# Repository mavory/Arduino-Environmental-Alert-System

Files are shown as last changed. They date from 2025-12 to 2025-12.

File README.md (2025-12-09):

# Arduino Environmental Alert System

It is a system that will allow you to monitor the temperature and humidity in your apartment, for example. It is very easy to set up and allows you to do a lot of things.

## Why did I do this?

I wanted to create some project with Arduino that could measure temperature and humidity and then send it to a PC. I also wanted to experiment and this seemed like a good idea.

## Features

- Ability to send emails
- Ability to create graphs and data into tables
- 24/7 monitoring possible
- Buzzer warning when limits are exceeded

## Scripts

Everything works on the Arduino code, which collects data and then the Python code on the PC monitors it.

## How it works?

The DHT11 sends information to the Arduino, which is programmed to send information at 9600. It is then taken over by python code, which monitors the information and if the temperature/humidity is outside the allowed range, it sends an email!

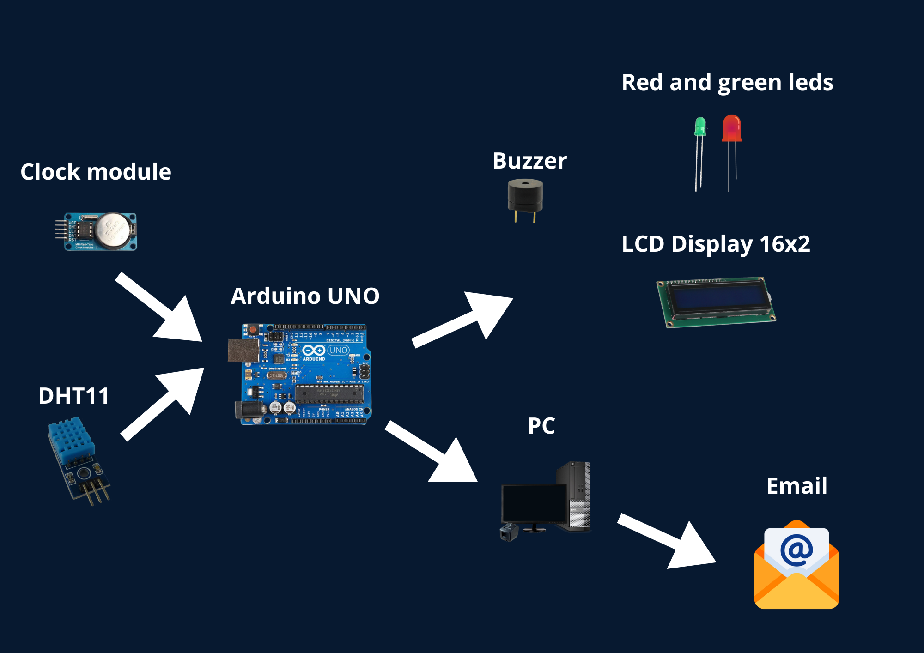
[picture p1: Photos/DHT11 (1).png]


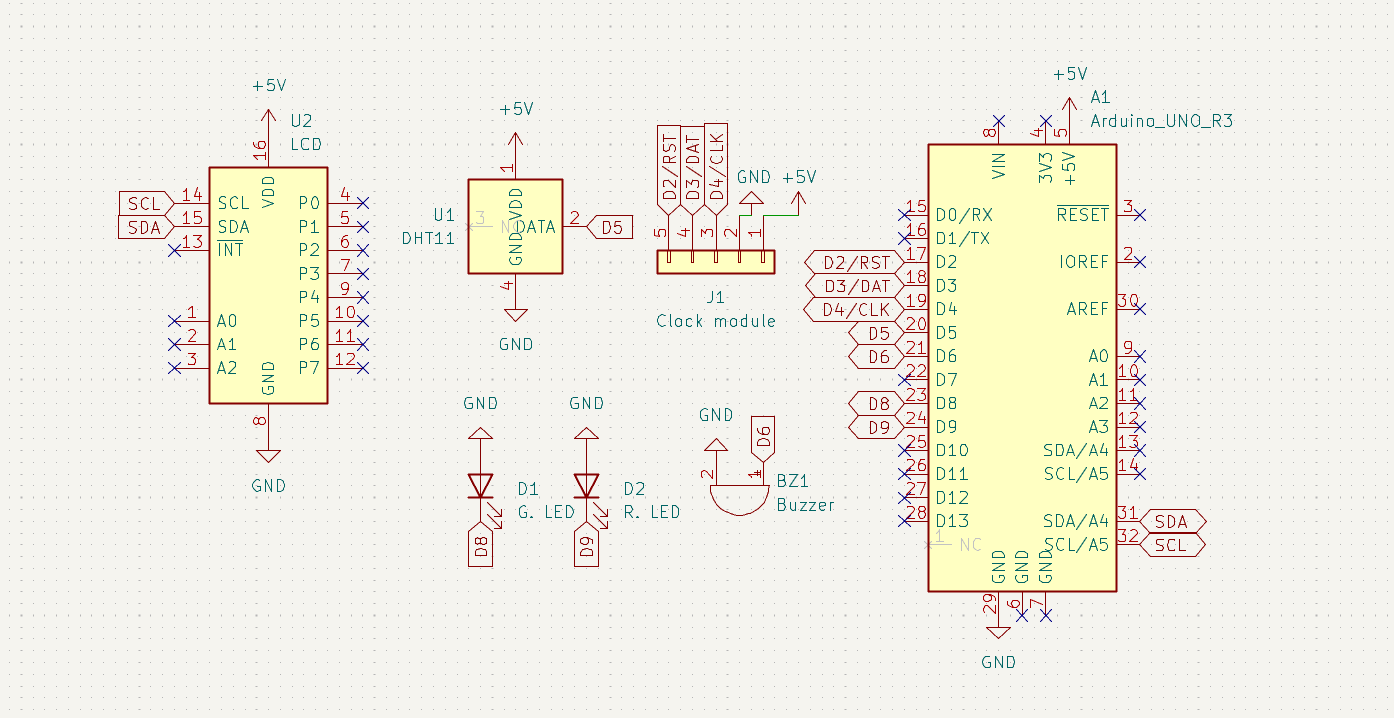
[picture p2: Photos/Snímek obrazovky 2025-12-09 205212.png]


## 3D models

Here is a view of the top and bottom of the case:

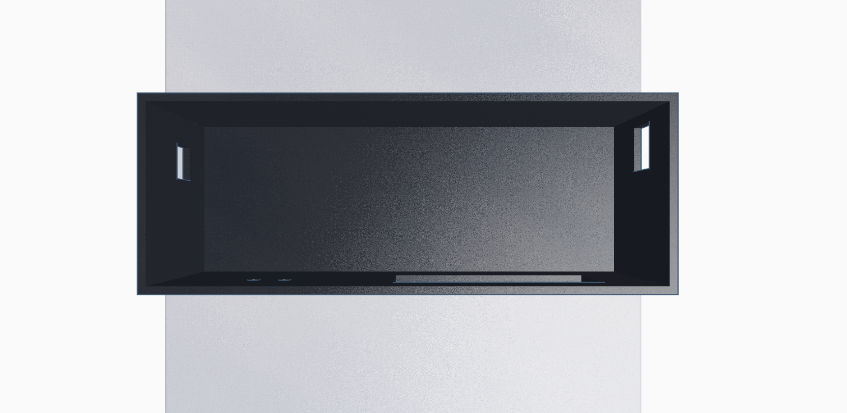
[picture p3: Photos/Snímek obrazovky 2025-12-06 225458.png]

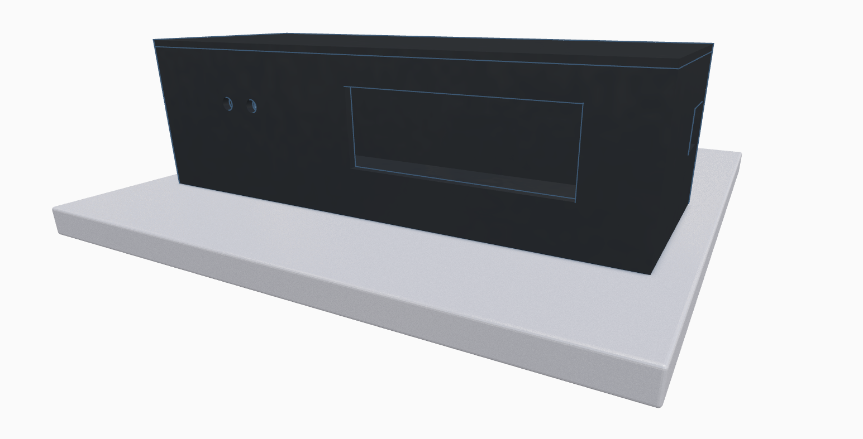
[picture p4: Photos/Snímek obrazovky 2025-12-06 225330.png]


## Here is the final image of how it works!



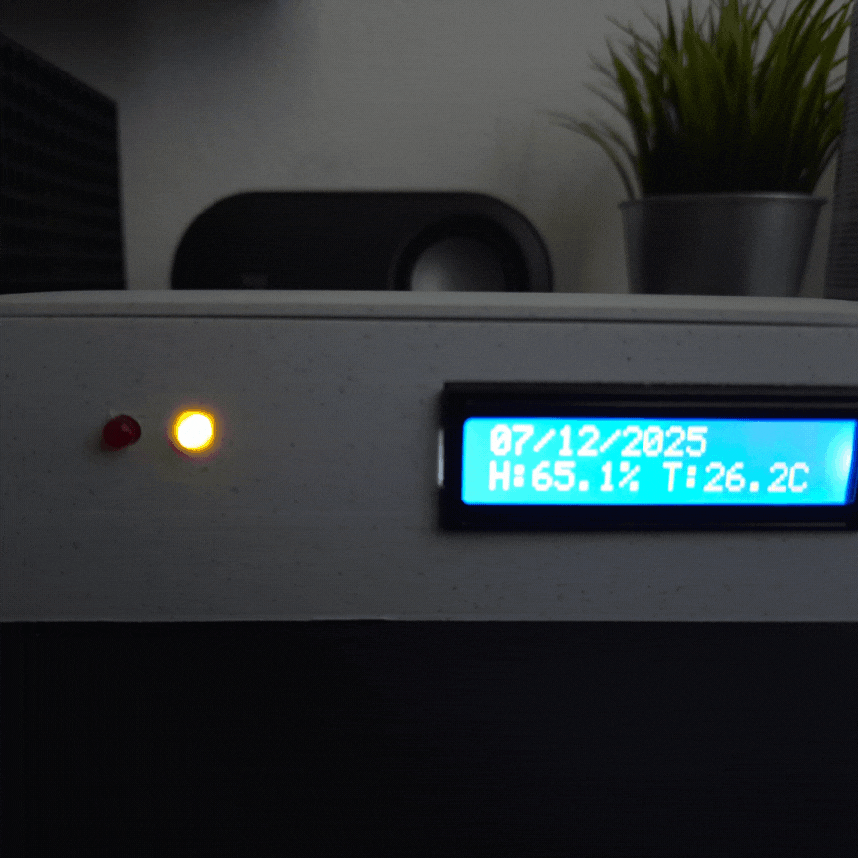
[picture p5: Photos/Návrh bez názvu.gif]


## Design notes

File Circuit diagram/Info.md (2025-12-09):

# Wiring
### DHT11 Sensor

- GND: GND
- VCC: 5V
- DATA: D5

### LCD Display

- GND: GND
- VCC: 5V
- SDA: A4
- SCL: A5

### Buzzer

- Pin: D6
- GND: GND

### Green and red led

- Green: D8
- Red: D9
- GND: GND

### Clock module

- GND: GND
- VCC: 5V
- CLK: D4
- DAT: D3
- RST: D2

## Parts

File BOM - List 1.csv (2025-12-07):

Item | Quantity | Link
Arduino UNO R3 | 1 | https://www.aliexpress.com/item/1005009161334072.html?curPageLogUid=n2sKRZSiC7X8
Green led | 1 | https://www.aliexpress.com/item/1005004453741169.html?scm_id=1007.14452.396806.0&scm-url=1007.14452.396806.0
Red led | 1 | https://www.aliexpress.com/item/1005004453741169.html?scm_id=1007.14452.396806.0&scm-url=1007.14452.396806.0
Breadboard | 1 | https://www.aliexpress.com/item/1005009799908389.html
DHT11 | 1 | https://www.aliexpress.com/item/32997407491.html?curPageLogUid=FQjsx9HCVnmy
Buzzer | 1 | https://www.aliexpress.com/item/1005010321957502.html?curPageLogUid=pNY8QTDdxUFY
Cables | Much | https://www.aliexpress.com/item/1005002611994443.html?curPageLogUid=fx2zB0EGcu5H
LCD 16x2 | 1 | https://www.aliexpress.com/item/1005010345517169.html?curPageLogUid=SbTSyaXiciNx
RTC module | 1 | https://www.aliexpress.com/item/32948191960.html?curPageLogUid=74KaBoIFDABx

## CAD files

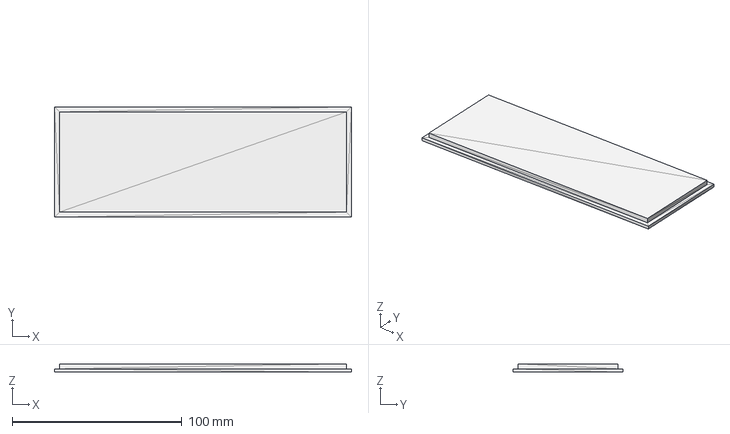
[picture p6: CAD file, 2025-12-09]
CAD/Top.step
175.0 x 65.0 x 5.00 mm

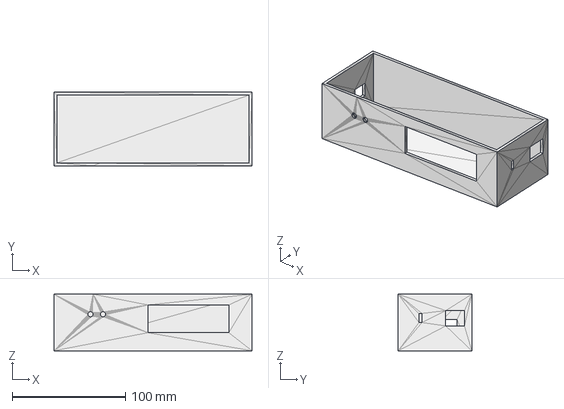
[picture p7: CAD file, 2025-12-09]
CAD/Bottom.step
175.0 x 65.0 x 50.0 mm

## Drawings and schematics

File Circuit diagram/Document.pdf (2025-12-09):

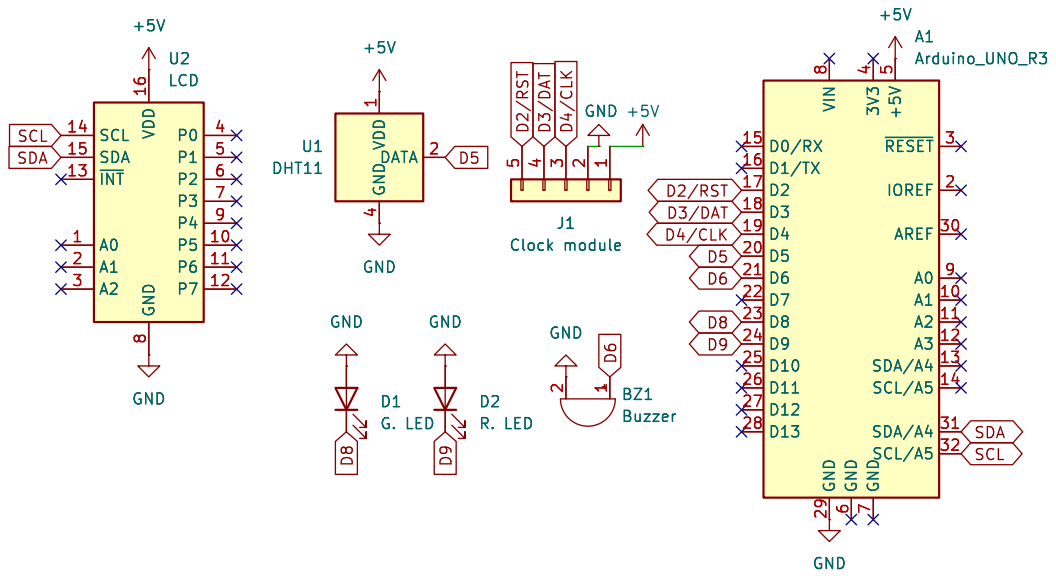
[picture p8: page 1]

1BZ1 Buzzer +5V +5V GND GND GND D2 R. LED GND VDD

4 DATA U1 2 DHT11 D0/RX 15 D1/TX 16 D2 17 D3 18 D4 19 D5 20 D6 21 D7 22 D8 23 D9 24 D10 25 D11 26 D12 27 D13 28 VIN

Id: 1/1 Title: File: New.kicad_sch Sheet: / D1 G. LED

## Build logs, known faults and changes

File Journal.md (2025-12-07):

# My Journal

This is the journal where I created a project with Arduino.

## So how much time did I spend on that?

In total, I spent about over 13 hours on it...

## My worst hangups

- I couldn't even put the leds in the holes, so I had to grind it all down.
- The RTC module was also giving me weird dates, but I fixed that.
- I made a few coding mistakes.

## Timeline

I thought I would create a system that would monitor temperature and humidity using Arduino and then send the information to Gmail. First I drew everything and started working on it:



Next, I started creating a GitHub repo and created folders. I also found all the parts so I could put it together. I thought for a while about using RTC, but I got over it and used it.



I started testing all the components to see if they worked. The LCD worked, the Buzzer too... But I forgot to set the RTC, so it told me that today is the year 2087 😭

This: 2087-31-12 03:27:00

I solved the problem by resetting the RTC and I was able to continue building.



After testing the components, I jumped into making the 3D case. I took all my measurements and started modeling the bottom part. I gave each piece a small tolerance so it would fit nicely. When I had the bottom finished, I just tried it out to see if everything fit and it did! So I moved on to the top part, which was easy to model.



When I had the 3D case ready, I started connecting the components. A few times some of the cables fell out, but that was probably the worst problem.



Unfortunately I found a minor problem that I hadn't noticed before. The DHT11 connection is completely extruded, so I had to adjust a few things on the bottom and it should be good now.

After editing the 3D case, I jumped into coding the Arduino. I just wanted the basic logic for the system to send information to the serial monitor, which would then be taken over by the python code, which would then do more things.
I experimented with libraries a few times, but after a while I decided to use the ones in the picture now.



Once I had the code without errors (hopefully), I could start testing if everything is working properly. I tested if the RTC is showing a good date, and it is. I also tested the sensor to see if it is sending good information and it seems that everything is working perfectly so far!
In the meantime, I printed the bottom part so it would be finished as soon as possible.



Meanwhile, while the bottom part was printing, I started creating python code that would take values from the Arduino and then send emails using Google Code. At first I didn't know how to do it, but then I added things gradually and it became a working code.

When the bottom part was printed, I took it off the printer and prepared a breadboard and components so I could put them inside. It all worked out, but there were a few problems...
The holes for the LEDs were too small, so I had to grind them down and they ended up getting in there. I also kept disconnecting the cables from the components, but I fixed that. Then I had it all ready and tested to see if everything worked. And it did!
Just print the top part, tweak a few things, set the code and everything should hopefully work.



I already printed the top part. I put it on top of it and it fit perfectly. I saved the Python code and created a code in Google settings so I could send emails.I was looking for that setting for a while, but after some time I found it.

After about 13 hours of work, I finished this project. Everything works and fits.
I'm very glad it works!

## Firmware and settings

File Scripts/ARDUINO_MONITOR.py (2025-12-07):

import serial
import time
import csv
import pandas as pd
import matplotlib.pyplot as plt
from datetime import datetime
from email.mime.multipart import MIMEMultipart
from email.mime.image import MIMEImage
import os
# Poznámka: smtplib, MIMEText se importují až ve funkci.

# --- SETTINGS ---
PORT = "COM3"
RATE = 9600
MAIL_FROM = "EMAIL!!!"
APP_PASS = "GOOGLE CODE!!!" # Zabezpečené heslo aplikace

# --- TARGETS & FILES ---
MAIL_TO = "EMAIL!!!!"
CSV_FILE = "data.csv"
H_GRAPH = "humid_graph.png"
T_GRAPH = "temp_graph.png"

# --- LIMITS ---
H_min = 30.0
H_max = 70.0
T_min = 15.0
T_max = 30.0

# state: 1=OK, 0=OUT_OF_LIMIT
H_state = 1
T_state = 1

def send_report(subject, body_html, attachments=None):
    
    import smtplib
    from email.mime.text import MIMEText
    
    msg = MIMEMultipart('related') 
    msg['Subject'] = subject
    msg['From'] = MAIL_FROM
    msg['To'] = MAIL_TO
    
    msg.attach(MIMEText(body_html, 'html'))

    # Poznámka: Prilohy se posilaji pouze pri alarmech/navratu
    if attachments:
        for attachment_path in attachments:
            if not os.path.exists(attachment_path):
                print(f"ERROR: Attachment file not found: {attachment_path}")
                continue
            
            with open(attachment_path, 'rb') as f:
                img = MIMEImage(f.read())
                
            img.add_header('Content-ID', f'<{os.path.basename(attachment_path)}>')
            msg.attach(img)


    try:
        s = smtplib.SMTP_SSL('smtp.gmail.com', 465)
        s.login(MAIL_FROM, APP_PASS)
        s.send_message(msg)
        s.quit()
        print("INFO: Email OK.")
    except Exception as e:
        print(f"ERROR: Email failed: {e}")

def get_data(line):
    
    try:
        line = line.strip()
        
        if "H:" in line and "T:" in line:
            
            # jednodussi parsovani, vice chybove (pozn.: lidska chyba)
            parts = line.split(" ") 
            
            hum = float(parts[0].replace("H:", ""))
            temp = float(parts[1].replace("T:", ""))

            return hum, temp

        if "ERROR" in line:
            print("ERROR: Sensor reported an issue.")
            return None

    except Exception as e:
        print(f"ERROR: Parsing error on line '{line}': {e}")
        
    return None

def check_limits(humidity, temperature):
    global H_state, T_state

    # Priprava tela zprava (HTML) a casu udalosti
    event_time = datetime.now().strftime("%Y-%m-%d %H:%M:%S")
    
    # HTML s inline obrazky
    body_template = f"""
    <html>
    <body style="font-family: Arial, sans-serif; font-size: 14px;">
        <h2 style="color: #333;">Monitoring Report</h2>
        <ul style="list-style-type: none; padding: 0;">
            <li style="margin-bottom: 5px;"><b>EVENT TIME:</b> {event_time}</li>
            <li style="margin-bottom: 5px;"><b>Current Humidity:</b> {humidity:.1f}% (Limit: {H_min}% - {H_max}%)</li>
            <li style="margin-bottom: 10px;"><b>Current Temperature:</b> {temperature:.1f}&#8451; (Limit: {T_min}&#8451; - {T_max}&#8451;)</li>
            <li><b>Status:</b> {{status}}</li>
        </ul>
        <hr>
        
        <h3 style="color: #555;">Recent Data Overview:</h3>
        <p><b>Humidity:</b></p>
        <img src="cid:{H_GRAPH}" alt="Humidity Graph">
        <p><b>Temperature:</b></p>
        <img src="cid:{T_GRAPH}" alt="Temperature Graph">
        
    </body>
    </html>
    """
    
    attachments = [H_GRAPH, T_GRAPH]


    # 1. Humidity Check
    if humidity < H_min or humidity > H_max:
        if H_state != 0:
            H_state = 0
            
            # ALARM
            subject = "ALARM: Humidity Out of Range!"
            body = body_template.replace("{{status}}", '<span style="color:red; font-weight:bold;">HUMIDITY OUT OF LIMIT</span>')
            send_report(subject, body, attachments) # Poslat s prilohou
            
    elif H_state != 1:
        H_state = 1
        
        # RETURN TO NORMAL
        subject = "INFO: Humidity Back to Normal"
        body = body_template.replace("{{status}}", '<span style="color:green; font-weight:bold;">All within normal range</span>')
        send_report(subject, body, attachments) # Poslat s prilohou
        
        
    # 2. Temperature Check
    if temperature < T_min or temperature > T_max:
        if T_state != 0:
            T_state = 0
            
            # ALARM
            subject = "ALARM: Temperature Out of Range!"
            body = body_template.replace("{{status}}", '<span style="color:red; font-weight:bold;">TEMPERATURE OUT OF LIMIT</span>')
            send_report(subject, body, attachments) # Poslat s prilohou
            
    elif T_state != 1:
        T_state = 1
        
        # RETURN TO NORMAL
        subject = "INFO: Temperature Back to Normal"
        body = body_template.replace("{{status}}", '<span style="color:green; font-weight:bold;">All within normal range</span>')
        send_report(subject, body, attachments) # Poslat s prilohou


def csv_write(h, t):
    
    now = datetime.now()
    try:
        with open(CSV_FILE, mode='a', newline='') as f:
            csv_writer = csv.writer(f)
            csv_writer.writerow([now.strftime("%Y-%m-%d %H:%M:%S"), h, t])
    except Exception as e:
        print(f"ERROR: CSV write failed: {e}")

def graph_make():
    try:
        # Poznámka: Jde o rychlou a ne moc cistou implementaci Pandas/Matplotlib
        df = pd.read_csv(CSV_FILE, header=None, names=["time", "H", "T"], parse_dates=["time"])
        
        # H graph
        plt.figure(figsize=(7, 3.5)) 
        plt.plot(df["time"], df["H"])
        plt.title("H Humidity")
        plt.grid(True)
        plt.savefig(H_GRAPH)
        plt.close()
        
        # T graph
        plt.figure(figsize=(7, 3.5))
        plt.plot(df["time"], df["T"], color='red')
        plt.title("T Temperature")
        plt.grid(True)
        plt.savefig(T_GRAPH)
        plt.close()
        
    except Exception as e:
        # Tiskne se pouze pri skutecne chybe, ne pri startu (prazdny soubor)
        if "No columns to parse" not in str(e) and not os.path.exists(CSV_FILE):
            print(f"ERROR: Graphs failed: {e}")


# --- MAIN CODE ---
if __name__ == '__main__':

    try:
        # Ujisti se, ze soubor pro data existuje
        with open(CSV_FILE, 'a'):
            pass
        
        # Start message - BEZ PŘÍLOHY (jak bylo požadováno)
        start_body = f"""
        <html><body style="font-family: Arial, sans-serif;">
            <p>The monitoring script started at {datetime.now().strftime("%Y-%m-%d %H:%M:%S")}.</p>
        </body></html>
        """
        send_report("INFO: Script Started", start_body, attachments=None)

        ser = serial.Serial(PORT, RATE, timeout=1)
        print(f"START: Listening on {PORT}...")
        time.sleep(2) 

        while True:
            if ser.in_waiting > 0:
                line = ser.readline().decode("utf-8").strip()
                print(f"Received: {line}")

                measurement = get_data(line)

                if measurement is not None:
                    h, t = measurement
                    csv_write(h, t) 
                    graph_make() 
                    check_limits(h, t) 

            time.sleep(2) 

    except serial.SerialException as e:
        print(f"CRITICAL ERROR: Cannot open port {PORT}: {e}")
    except KeyboardInterrupt:
        print("\nEND: Stopped by user.")

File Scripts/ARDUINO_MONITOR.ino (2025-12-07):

#include <Wire.h>
#include <LiquidCrystal_I2C.h>
#include <ThreeWire.h>
#include <RtcDS1302.h>
#include <DHT.h>

LiquidCrystal_I2C lcd(0x27, 16, 2);

ThreeWire myWire(3, 4, 2); // dat, clk, rst!!!!!!!!!
RtcDS1302<ThreeWire> rtc(myWire);

#define DHTPIN 5
#define DHTTYPE DHT11
DHT dht(DHTPIN, DHTTYPE);

#define greenLed 8
#define redLed 9
#define buzzer 6

unsigned long lastBeepTime = 0;
bool beepState = false;
float lastHum = -1;
float lastTemp = -1;
bool sensorError = false;
unsigned long lastBlink = 0;
bool blinkState = false;

void fadeInDisplay(const char* l1, const char* l2) {
  lcd.clear();
  for (int i = 0; i <= 16; i++) {
    lcd.setCursor(0, 0);
    lcd.print(String(l1).substring(0, i));
    lcd.setCursor(0, 1);
    lcd.print(String(l2).substring(0, i));
    delay(40);
  }
}

void setup() {
  Serial.begin(9600);
  lcd.begin(16, 2);
  lcd.backlight();

  pinMode(greenLed, OUTPUT);
  pinMode(redLed, OUTPUT);
  pinMode(buzzer, OUTPUT);
  digitalWrite(buzzer, LOW);

  rtc.Begin();
  dht.begin();

  if (!rtc.GetIsRunning()) {
    rtc.SetDateTime(RtcDateTime(__DATE__, __TIME__));
  }

  fadeInDisplay("  System Start  ", "   Initializing ");
  delay(500);
  lcd.clear();
}

void loop() {
  float hum = dht.readHumidity();
  float temp = dht.readTemperature();
  RtcDateTime now = rtc.GetDateTime();

  char dateBuffer[17];
  snprintf(dateBuffer, sizeof(dateBuffer), "   %02u/%02u/%04u   ",
           now.Day(), now.Month(), now.Year());

  if (!isnan(hum) && !isnan(temp)) {
    if (sensorError) {
      lcd.clear();
      sensorError = false;
    }

    bool outOfRange = (hum < 30.0 || hum > 70.0);
    digitalWrite(greenLed, outOfRange ? LOW : HIGH);
    digitalWrite(redLed,   outOfRange ? HIGH : LOW);

    if (outOfRange) {
      if (millis() - lastBeepTime > 1000) {
        beepState = !beepState;
        digitalWrite(buzzer, beepState);
        lastBeepTime = millis();
      }
    } else {
      digitalWrite(buzzer, LOW);
    }

    if (abs(hum - lastHum) >= 0.1 || abs(temp - lastTemp) >= 0.1 || lastHum < 0) {
      char humBuf[6], tempBuf[6];
      dtostrf(hum, 4, 1, humBuf);
      dtostrf(temp, 4, 1, tempBuf);

      lcd.setCursor(0, 0);
      lcd.print(dateBuffer);

      lcd.setCursor(0, 1);
      lcd.print(" ");
      lcd.print(humBuf);
      lcd.print("% | ");
      lcd.print(tempBuf);
      lcd.print((char)223);
      lcd.print("C ");

      Serial.print("H:");
      Serial.print(humBuf);
      Serial.print(",T:");
      Serial.println(tempBuf);

      lastHum = hum;
      lastTemp = temp;
    }

  } 

  else {
    if (!sensorError) {
      lcd.clear();
      lcd.setCursor(0, 0);
      lcd.print(" NO SENSOR DATA ");
      Serial.println("ERROR:SENSOR");
      sensorError = true;
    }

    if (millis() - lastBlink > 500) {
      blinkState = !blinkState;
      digitalWrite(greenLed, blinkState);
      digitalWrite(redLed, !blinkState);
      lastBlink = millis();
    }

    digitalWrite(buzzer, LOW);
  }

  delay(250);
}

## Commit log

2025-12-06 Create Arduino
2025-12-07 3D models
    [bottom-arduino.stl, top-arduino.stl]
2025-12-07 Arduino IDE
2025-12-09 Step files
    [Bottom.step, Top.step]
2025-12-09 Arduino Pinout Documentation
    Updated formatting for wiring instructions and added consistent markdown headers.
2025-12-09 Arduino Pinout Documentation
